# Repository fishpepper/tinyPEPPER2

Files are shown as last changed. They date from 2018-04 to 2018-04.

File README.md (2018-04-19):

# tinyPEPPER2 -- a tiny and lightweight 4in1 BLHeli_S ESC -- 2S edition

My approach to build a small and lightweight ESC.

See [http://fishpepper.de/projects/tinyPEPPER2](http://fishpepper.de/projects/tinyPEPPER2) for more details.

tinyPEPPER2 image

As [my previous tinyPEPPER 1S design](http://fishpepper.de/projects/tinyPEPPER), this thing is TINY as well! The outer dimensions are 20x20mm with a 16mm hole-to-hole spacing.
Of course it also runs BLHELI_S.

Key features:
- 16x16mm hole-to-hole spacing
- 1.4g (!)
- BLHeli_S with DSHOT300
- 1S or 2S operation
- 4.8 A continous current

This work is published under the CERN open hardware license v1.2. 
Feel free to use the design - but make sure to give proper credit 
and release all modifications under the same license! 
See LICENSE.txt for details!

THIS COMES WITH NO WARRANTY! BUILD, FLY, AND USE AT YOUR OWN RISK!

# Build your own

Make sure to init the git submodule for the libraries in the
kicad_misc directory by calling git submodule init && git submodule update.
You will have to use a recent kicad version, i used the commit #efdfaeb
when i designed this circuit board. Older versions will probably not work.

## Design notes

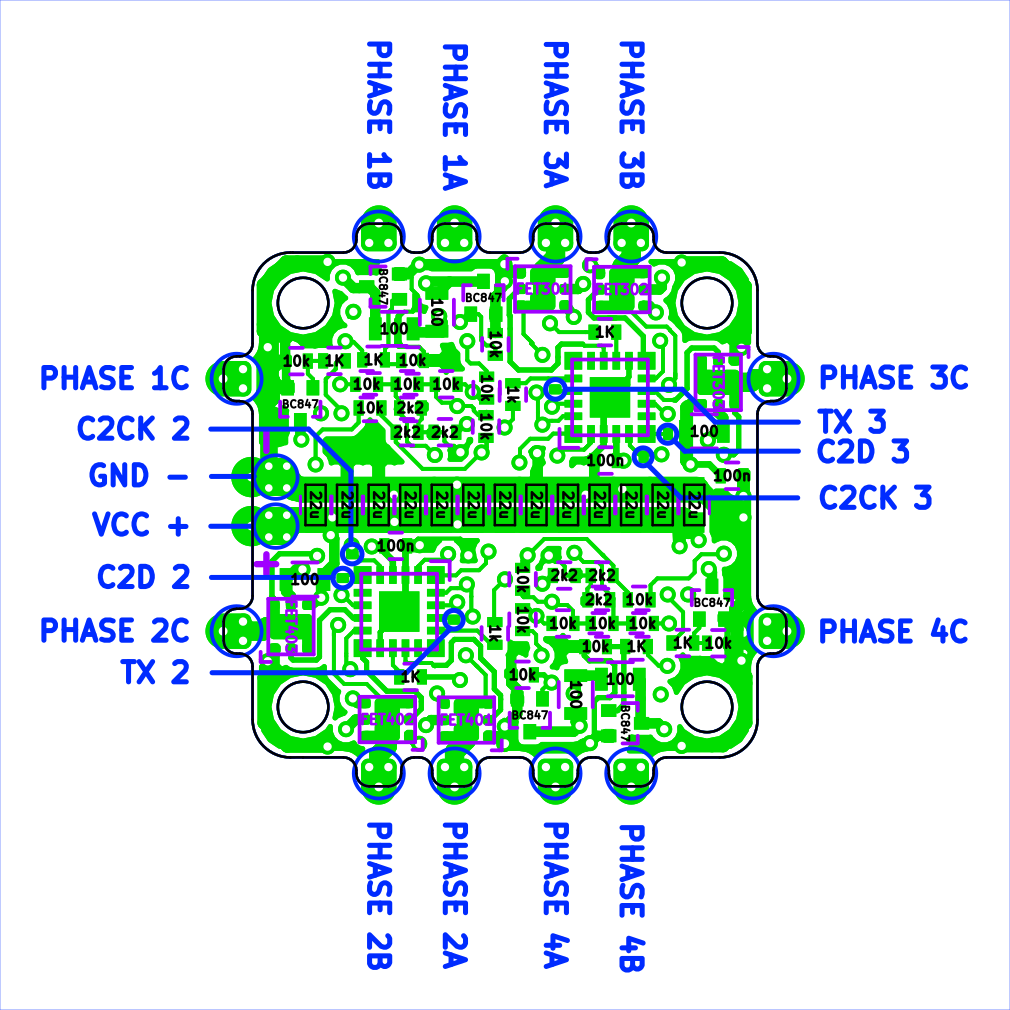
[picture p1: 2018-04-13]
doc/placement_back.png

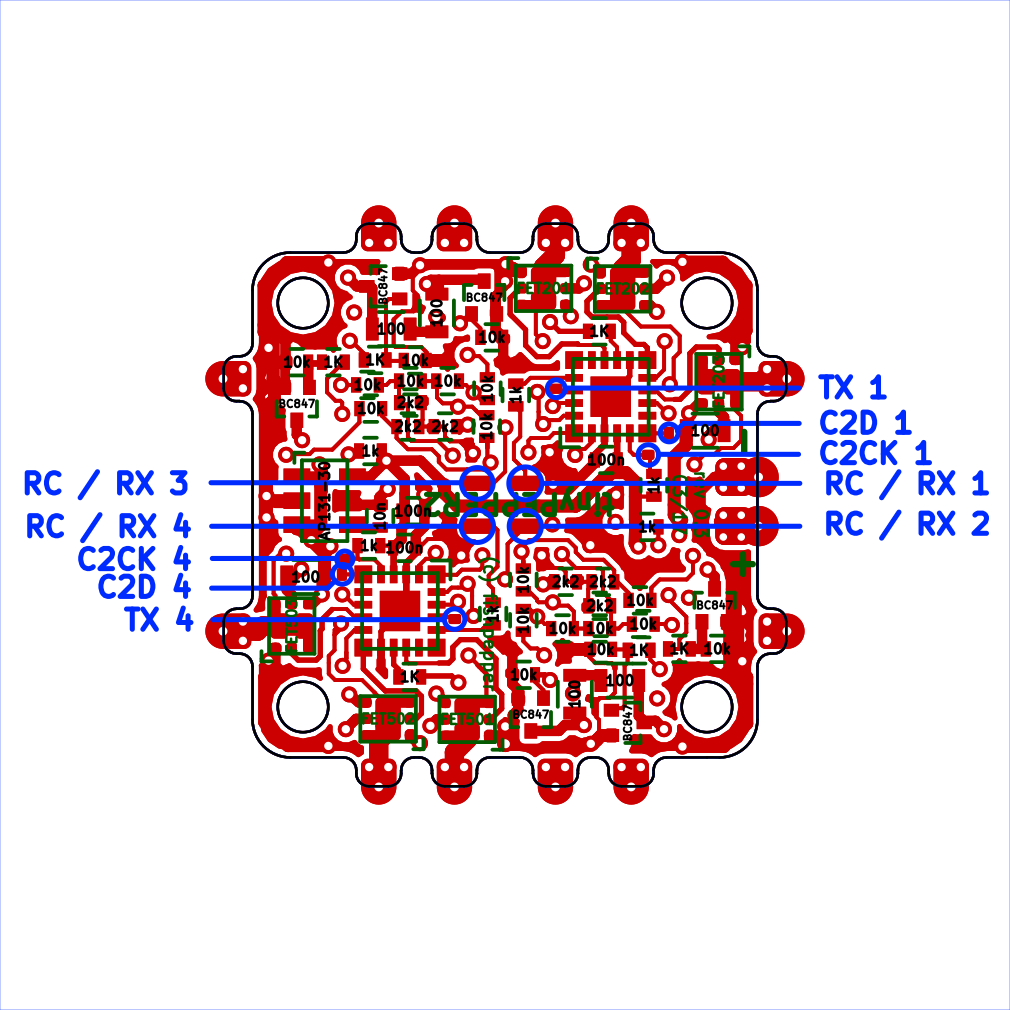
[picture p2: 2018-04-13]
doc/placement_front.png

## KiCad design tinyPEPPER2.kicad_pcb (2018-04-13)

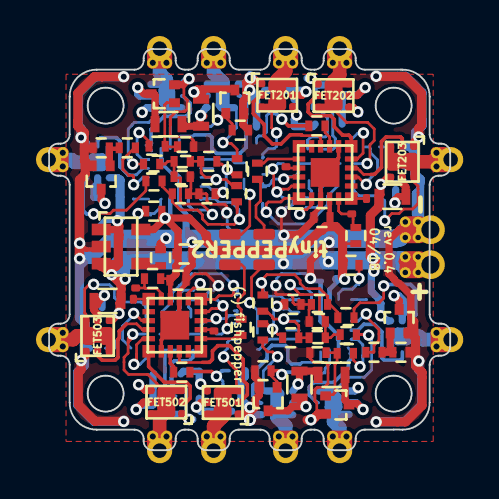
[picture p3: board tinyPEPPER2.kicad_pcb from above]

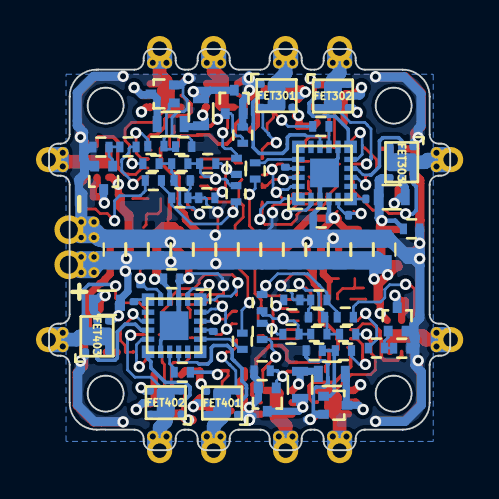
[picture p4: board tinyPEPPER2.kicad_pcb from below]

Board: 4 copper layers, 22.3 x 22.3 mm, 163 parts (82 on the bottom side), 100 nets.

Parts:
BL_TX201, BL_TX301, BL_TX401, BL_TX501: TP; TP_smd_0.5x0.4
C201, C301, C401, C501, C1001, C1002: 100n; C_0402_CUSTOM
C202, C203, C204, C302, C303, C304, C402, C403, C404, C502, C503, C504, C1000: 22u; C_0603_CUSTOM
C1003: 10n; C_0402_CUSTOM
FET201, FET202, FET203, FET301, FET302, FET303, FET401, FET402, FET403, FET501, FET502, FET503: UT6MA3; DFN2020-8D
H1, H2, H3, H4: hole; mouting_hole
OUT_A201, OUT_A301, OUT_A401, OUT_A501: TP; TP_PHASE_PAD
OUT_B201, OUT_B301, OUT_B401, OUT_B501: TP; TP_PHASE_PAD
OUT_C201, OUT_C301, OUT_C401, OUT_C501: TP; TP_PHASE_PAD
R201, R220, R301, R320, R401, R420, R501, R520: 1k; R_0402_CUSTOM
R202, R203, R204, R205, R206, R207, R217, R218, R219, R302, R303, R304, R305, R306, R307, R317, R318, R319, R402, R403, R404, R405, R406, R407, R417, R418, R419, R502, R503, R504, R505, R506, R507, R517, R518, R519: 10k; R_0402_CUSTOM
R208, R209, R210, R308, R309, R310, R408, R409, R410, R508, R509, R510: 2k2; R_0402_CUSTOM
R211, R212, R213, R311, R312, R313, R411, R412, R413, R511, R512, R513: 1K; R_0402_CUSTOM
R214, R215, R216, R314, R315, R316, R414, R415, R416, R514, R515, R516: 100; R_0603_CUSTOM
T201, T202, T203, T301, T302, T303, T401, T402, T403, T501, T502, T503: BC847; SC75
TP10, TP12: TP; TP_POWER_PAD_DOUBLESIDED
TP103, TP104, TP105, TP106: TP; tp_SMD_0.6x1.2
TP202, TP203, TP302, TP303, TP402, TP403, TP502, TP503: TP; TP_smd_0.5x0.4
U1: AP131-30; SOT-23-5
U201, U301, U401, U501: EFM8BB10; QFN20

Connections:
/RC_IN_0: R220.1, TP103.1
/RC_IN_1: R320.1, TP104.1
/single esc 1/3V3: C201.2, C301.2, C401.2, C501.2, C1001.1, R201.1, R301.1, R401.1, R501.1, U1.5, U201.4, U301.4, U401.4, U501.4
/single esc 1/Ac_0: R211.2, U201.13
/single esc 1/Ap_0: FET201.2, U201.14
/single esc 1/Bc_0: R212.2, U201.10
/single esc 1/Bp_0: FET202.2, U201.11
/single esc 1/C2CK_0: R201.2, TP203.1, U201.5
/single esc 1/C2D_0: TP202.1, U201.6
/single esc 1/PHASE_A_0: FET201.3, FET201.6, FET201.7, FET201.8, OUT_A201.1, R203.2
/single esc 1/PHASE_B_0: FET202.3, FET202.6, FET202.7, FET202.8, OUT_B201.1, R205.2
/single esc 1/PHASE_C_0: FET203.3, FET203.6, FET203.7, FET203.8, OUT_C201.1, R207.2
/single esc 2/Ac_0: R311.2, U301.13
/single esc 2/Ap_0: FET301.2, U301.14
/single esc 2/Bc_0: R312.2, U301.10
/single esc 2/Bp_0: FET302.2, U301.11
/single esc 2/C2CK_0: R301.2, TP303.1, U301.5
/single esc 2/C2D_0: TP302.1, U301.6
/single esc 2/PHASE_A_0: FET301.3, FET301.6, FET301.7, FET301.8, OUT_A301.1, R303.2
/single esc 2/PHASE_B_0: FET302.3, FET302.6, FET302.7, FET302.8, OUT_B301.1, R305.2
/single esc 2/PHASE_C_0: FET303.3, FET303.6, FET303.7, FET303.8, OUT_C301.1, R307.2
/single esc 3/Ac_0: R411.2, U401.13
/single esc 3/Ap_0: FET401.2, U401.14
/single esc 3/Bc_0: R412.2, U401.10
/single esc 3/Bp_0: FET402.2, U401.11
/single esc 3/C2CK_0: R401.2, TP403.1, U401.5
/single esc 3/C2D_0: TP402.1, U401.6
/single esc 3/PHASE_A_0: FET401.3, FET401.6, FET401.7, FET401.8, OUT_A401.1, R403.2
/single esc 3/PHASE_B_0: FET402.3, FET402.6, FET402.7, FET402.8, OUT_B401.1, R405.2
/single esc 3/PHASE_C_0: FET403.3, FET403.6, FET403.7, FET403.8, OUT_C401.1, R407.2
/single esc 3/RC_IN: R420.1, TP105.1
/single esc 4/Ac_0: R511.2, U501.13
/single esc 4/Ap_0: FET501.2, U501.14
/single esc 4/Bc_0: R512.2, U501.10
/single esc 4/Bp_0: FET502.2, U501.11
/single esc 4/C2CK_0: R501.2, TP503.1, U501.5
/single esc 4/C2D_0: TP502.1, U501.6
/single esc 4/PHASE_A_0: FET501.3, FET501.6, FET501.7, FET501.8, OUT_A501.1, R503.2
/single esc 4/PHASE_B_0: FET502.3, FET502.6, FET502.7, FET502.8, OUT_B501.1, R505.2
/single esc 4/PHASE_C_0: FET503.3, FET503.6, FET503.7, FET503.8, OUT_C501.1, R507.2
/single esc 4/RC_IN: R520.1, TP106.1
GND: C201.1, C202.1, C203.1, C204.1, C301.1, C302.1, C303.1, C304.1, C401.1, C402.1, C403.1, C404.1, C501.1, C502.1, C503.1, C504.1, C1000.1, C1001.2, C1002.2, C1003.2, FET201.1, FET202.1, FET203.1, FET301.1, FET302.1, FET303.1, FET401.1, FET402.1, FET403.1, FET501.1, FET502.1, FET503.1, R208.1, R209.1, R210.1, R217.1, R218.1, R219.1, R308.1, R309.1, R310.1, R317.1, R318.1, R319.1, R408.1, R409.1, R410.1, R417.1, R418.1, R419.1, R508.1, R509.1, R510.1, R517.1, R518.1, R519.1, T201.2, T202.2, T203.2, T301.2, T302.2, T303.2, T401.2, T402.2, T403.2, T501.2, T502.2, T503.2, TP12.1, U1.2, U201.3, U201.12, U201.21, U301.3, U301.12, U301.21, U401.3, U401.12, U401.21, U501.3, U501.12, U501.21
unnamed: BL_TX201.1, U201.18
unnamed: BL_TX301.1, U301.18
unnamed: BL_TX401.1, U401.18
unnamed: BL_TX501.1, U501.18
unnamed: C1003.1, U1.4
unnamed: FET201.5, R214.2, T201.3
unnamed: FET202.5, R215.2, T202.3
unnamed: FET203.2, U201.9
unnamed: FET203.5, R216.2, T203.3
unnamed: FET301.5, R314.2, T301.3
unnamed: FET302.5, R315.2, T302.3
unnamed: FET303.2, U301.9
unnamed: FET303.5, R316.2, T303.3
unnamed: FET401.5, R414.2, T401.3
unnamed: FET402.5, R415.2, T402.3
unnamed: FET403.2, U401.9
unnamed: FET403.5, R416.2, T403.3
unnamed: FET501.5, R514.2, T501.3
unnamed: FET502.5, R515.2, T502.3
unnamed: FET503.2, U501.9
unnamed: FET503.5, R516.2, T503.3
unnamed: R202.1, R204.1, R206.1, U201.19
unnamed: R202.2, R203.1, R208.2, U201.20
unnamed: R204.2, R205.1, R209.2, U201.2
unnamed: R206.2, R207.1, R210.2, U201.1
unnamed: R211.1, R217.2, T201.1
unnamed: R212.1, R218.2, T202.1
unnamed: R213.1, R219.2, T203.1
unnamed: R213.2, U201.8
unnamed: R220.2, U201.17
unnamed: R302.1, R304.1, R306.1, U301.19
unnamed: R302.2, R303.1, R308.2, U301.20
unnamed: R304.2, R305.1, R309.2, U301.2
unnamed: R306.2, R307.1, R310.2, U301.1
unnamed: R311.1, R317.2, T301.1
unnamed: R312.1, R318.2, T302.1
unnamed: R313.1, R319.2, T303.1
unnamed: R313.2, U301.8
unnamed: R320.2, U301.17
unnamed: R402.1, R404.1, R406.1, U401.19
unnamed: R402.2, R403.1, R408.2, U401.20
unnamed: R404.2, R405.1, R409.2, U401.2
unnamed: R406.2, R407.1, R410.2, U401.1
unnamed: R411.1, R417.2, T401.1
unnamed: R412.1, R418.2, T402.1
unnamed: R413.1, R419.2, T403.1
unnamed: R413.2, U401.8
unnamed: R420.2, U401.17
unnamed: R502.1, R504.1, R506.1, U501.19
unnamed: R502.2, R503.1, R508.2, U501.20
unnamed: R504.2, R505.1, R509.2, U501.2
unnamed: R506.2, R507.1, R510.2, U501.1
unnamed: R511.1, R517.2, T501.1
unnamed: R512.1, R518.2, T502.1
unnamed: R513.1, R519.2, T503.1
unnamed: R513.2, U501.8
unnamed: R520.2, U501.17
VCC: C202.2, C203.2, C204.2, C302.2, C303.2, C304.2, C402.2, C403.2, C404.2, C502.2, C503.2, C504.2, C1000.2, C1002.1, FET201.4, FET202.4, FET203.4, FET301.4, FET302.4, FET303.4, FET401.4, FET402.4, FET403.4, FET501.4, FET502.4, FET503.4, R214.1, R215.1, R216.1, R314.1, R315.1, R316.1, R414.1, R415.1, R416.1, R514.1, R515.1, R516.1, TP10.1, U1.1, U1.3

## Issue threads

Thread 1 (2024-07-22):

Missing Symbols?

Nightsd01, 2024-07-22:
I so badly want to open the schematic in KiCad, but when I try to I get errors about a BUNCH of missing symbols. I've installed all of the default KiCad symbol libraries. Do I really have to go through and figure out how to download all 20+ missing libraries manually, or is there an easier way?

The following libraries were not found:

power.lib
device.lib
transistors.lib
conn.lib
linear.lib
regul.lib
74xx.lib
....
{and many more}

Nightsd01, 2024-07-22:
Edit: Nevermind, it seems like it's mostly just invalid GND and VCC symbols that were unable to be automatically converted to open in KiCad 8, so just replacing those 2 symbols seems to have resolved the problem

Closed 2024-07-22.

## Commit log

2017-02-22 adding gate druiver
    [single_esc.sch, tinyPEPPER2.kicad_pcb, tinyPEPPER2.sch]
2017-02-23 routing test done
    [single_esc.sch, tinyPEPPER2.kicad_pcb, tinyPEPPER2.sch]
2017-02-23 first routing ok
    [single_esc.sch, tinyPEPPER2.kicad_pcb]
2017-02-24 added serial R
    [single_esc.sch, tinyPEPPER2.kicad_pcb, tinyPEPPER2.sch]
2017-02-24 4layer done
    [single_esc.sch, tinyPEPPER2.kicad_pcb, tinyPEPPER2.sch]
2017-02-24 minor cleanup of traces
    [tinyPEPPER2.kicad_pcb]
2017-03-06 added docs
    [single_esc.sch, tinyPEPPER2.kicad_pcb, tinyPEPPER2.sch]
2017-03-09 fixed npn T
    [single_esc.sch, tinyPEPPER2.kicad_pcb]
2017-03-15 new pads
    [single_esc.sch, tinyPEPPER2.kicad_pcb, tinyPEPPER2.sch]
2018-04-13 fixing sch
    [single_esc.sch, tinyPEPPER2.kicad_pcb, tinyPEPPER2.sch]
